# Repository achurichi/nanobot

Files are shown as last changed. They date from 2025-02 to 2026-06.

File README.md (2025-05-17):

# Nanobot

## About This Project

This project is designed for learning ROS 2 on a Jetson Nano-powered robot. It includes various features for perception, control, and simulation, such as:

- **LiDAR** for environment mapping and obstacle detection.
- **Depth Camera** for 3D vision and object recognition.
- **Motor Control with ROS 2 Control** for precise movement and actuation.
- **Navigation** with path planning and obstacle avoidance.
- **Gazebo Simulation** for testing and development in a virtual environment.

Nanobot

## Scripts

The `scripts` folder contains useful scripts to manage the project:

- **`dev.sh`**: Starts the Docker container with the development environment and connects to it.
  Can be called with the following optional parameters:
  - `rebuild`: Forces a rebuild of the Docker image.
  - `restart`: Forces a restart of the Docker container.
  - `<user>@<ip>:<path>`: Connects through SSH to a remote host using the given user, IP, and project path.
    > ⚠️ **Important:** SSH key-based authentication must be set up to enable automatic syncing.  
    > Generate a key pair if you don't already have one:
    >
    > ```bash
    > ssh-keygen
    > ```
    >
    > Then, copy your public key to the Jetson Nano:
    >
    > ```bash
    > ssh-copy-id <user>@<ip>
    > ```
- **`build.sh`**: Builds everything needed to run the real robot or the simulation (if run with the `sim` parameter).
- **`clean.sh`**: Removes the files generated during the build process.
- **`start.sh`**: Starts the robot or the simulation (if run with the `sim` parameter).
- **`monitor.sh`**: Runs rviz and rqt_image_view (call with `sim` parameter if running the simulation).
- **`magnetometer_calibration.py`**: Run it to get the calibration values for the magnetometer. Then update the values in `/ros_ws/src/nanobot_imu/config/imu.yaml`.

## Controlling the Robot

You can control the robot in three different ways:

- **Using a Joystick**  
   If you have a joystick connected via USB, the robot can be controlled directly through it.

  To use the Steam Deck joystick, enable gamepad mode by long-pressing the button with three dashes (≡). You can verify that the joystick is recognized by using the evtest tool.

- **Using the Web App**
  You can control the robot through a web interface. Open a browser and navigate to:  
   `http://<jetson-nano-ip>:5173`

- **Using the Keyboard**  
   To control the robot using the keyboard, run the following command:
  ```bash
   ros2 run teleop_twist_keyboard teleop_twist_keyboard --ros-args -r /cmd_vel:=/cmd_vel_joy
  ```

## Configure the Power Button

Ensure the power button is connected correctly to the Jetson Nano:

- Connect the power button to **Pin 1** and **Pin 2** of the header pins.
- Jumper **Pin 7** and **Pin 8** of the button header pins to disable the auto power on.

Open the `logind.conf` file to adjust the power button settings:

```bash
sudo nano /etc/systemd/logind.conf
```

Add the following lines to the file:

```bash
NAutoVTs=1
ReserveVT=1
HandlePowerKey=poweroff
```

The most reliable way to configure the power button to turn on/off the Jetson Nano is by disabling the graphical user interface (GUI), as GNOME interferes with the button behavior defined in `logind.conf`.

To boot with no GUI:

```bash
sudo systemctl set-default multi-user.target
```

Auto-login is required to allow SSH connections after the system boots up. To enable it, create a directory for custom configurations:

```bash
sudo mkdir /etc/systemd/system/getty@tty1.service.d/
```

Next, open the override configuration file:

```bash
sudo nano /etc/systemd/system/getty@tty1.service.d/override.conf
```

Add the following content to automatically log in your user:

```bash
[Service]
ExecStart=
ExecStart=-/sbin/agetty --noissue --autologin <user-name> %I $TERM
Type=idle
```

Replace `<user-name>` with your actual username.

Finally, reboot the system to apply the changes.

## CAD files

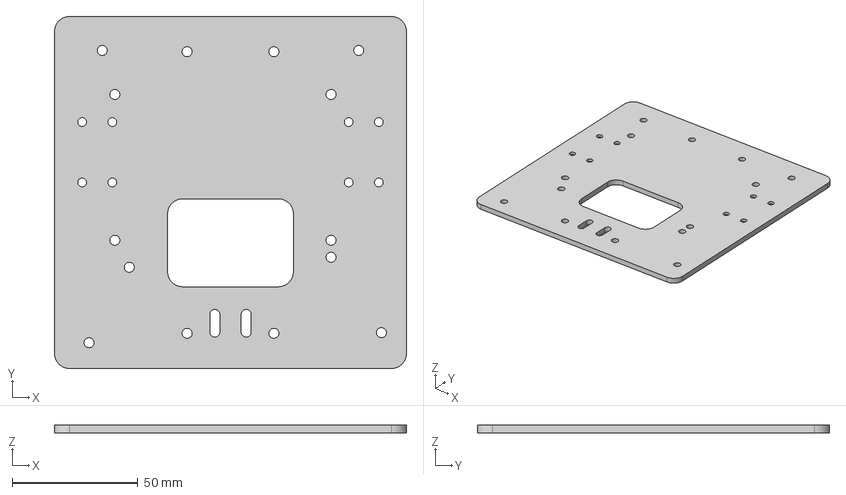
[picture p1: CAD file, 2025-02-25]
3d_parts/base.step
140.0 x 140.0 x 3.00 mm

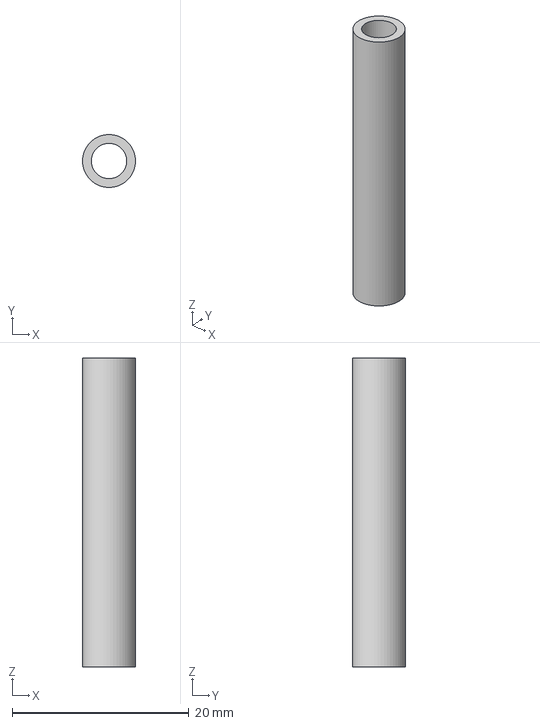
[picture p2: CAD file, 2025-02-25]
3d_parts/spacer_35mm.step
5.99 x 6.00 x 35.0 mm

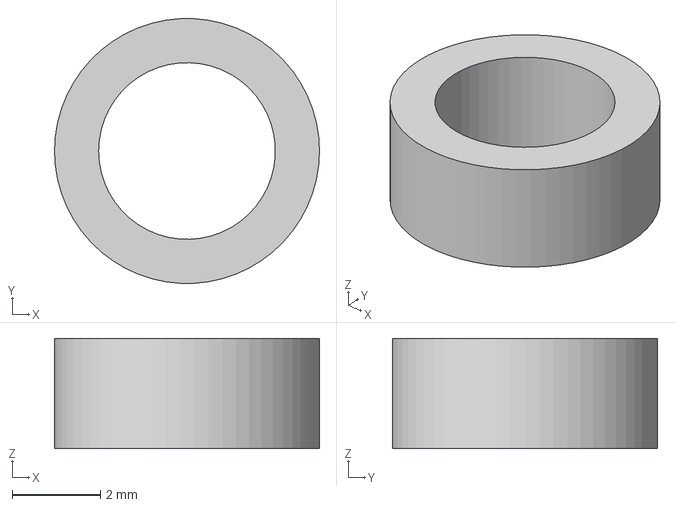
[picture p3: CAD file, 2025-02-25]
3d_parts/spacer_2_5mm.step
6.00 x 5.99 x 2.50 mm

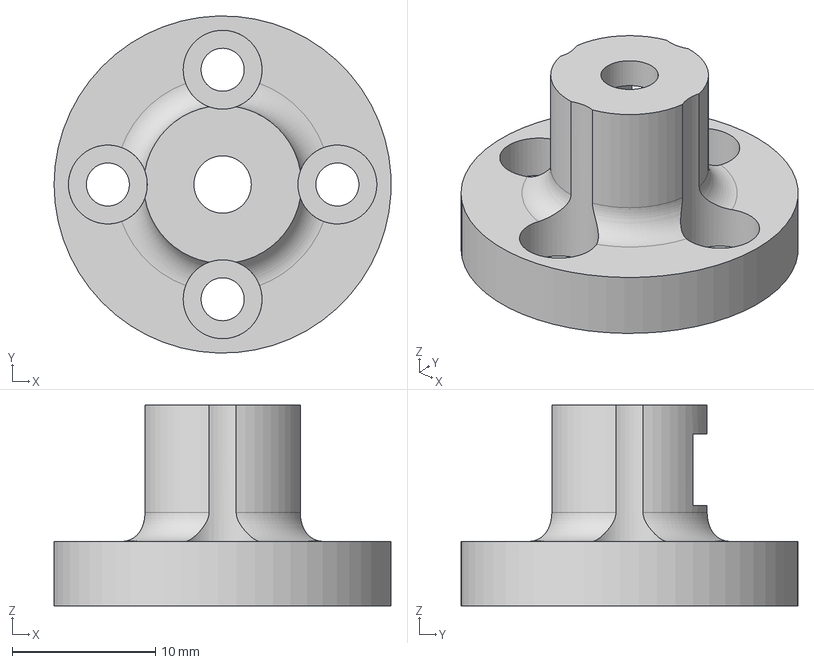
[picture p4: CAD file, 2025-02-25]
3d_parts/wheel_connector.step
23.5 x 23.5 x 14.0 mm

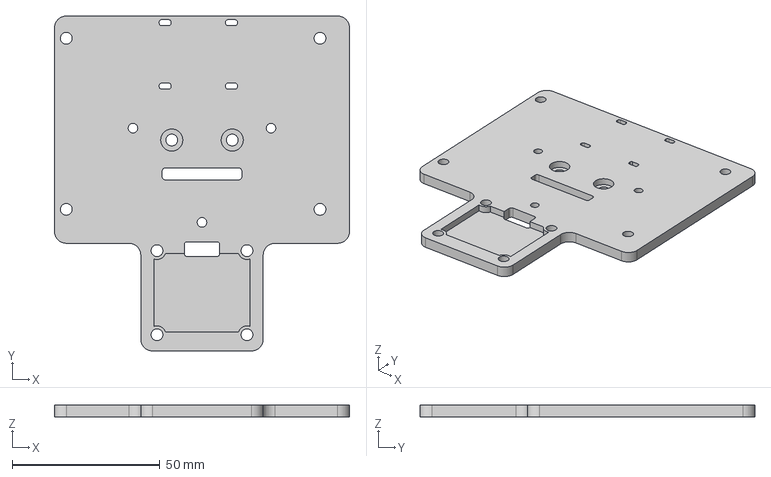
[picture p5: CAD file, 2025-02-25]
3d_parts/top.step
100.0 x 113.5 x 4.00 mm

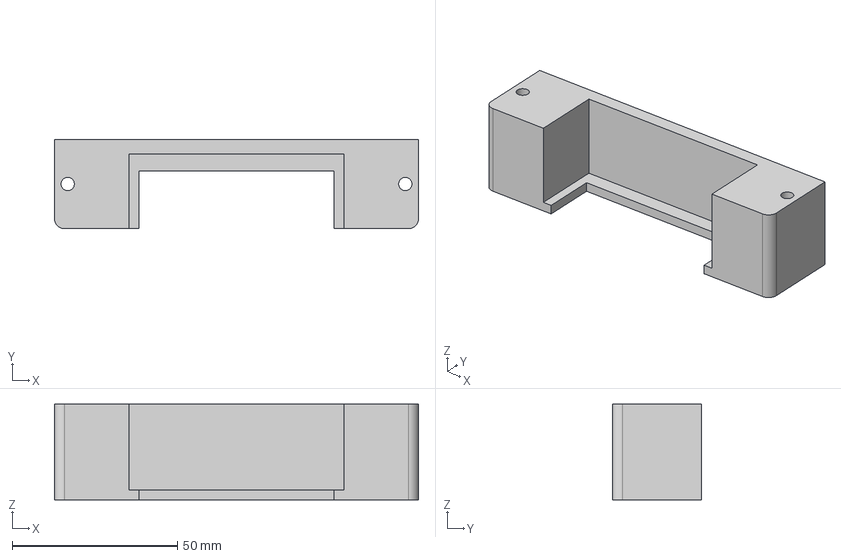
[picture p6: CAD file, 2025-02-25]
3d_parts/battery_holder_front.step
110.0 x 27.0 x 29.0 mm

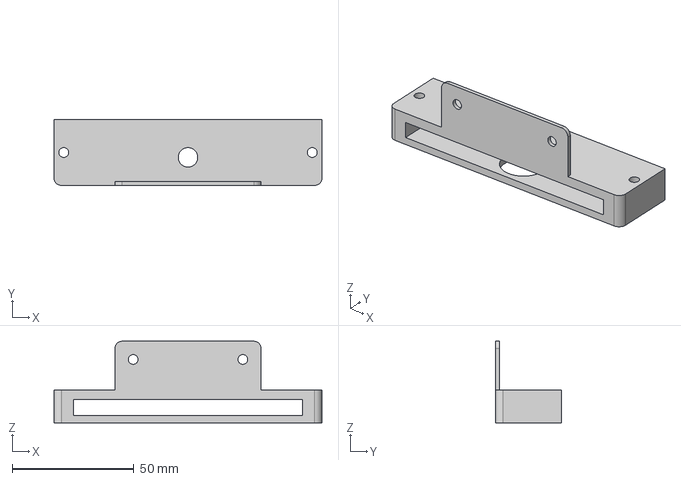
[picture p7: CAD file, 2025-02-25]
3d_parts/camera_holder.step
110.0 x 27.0 x 33.5 mm

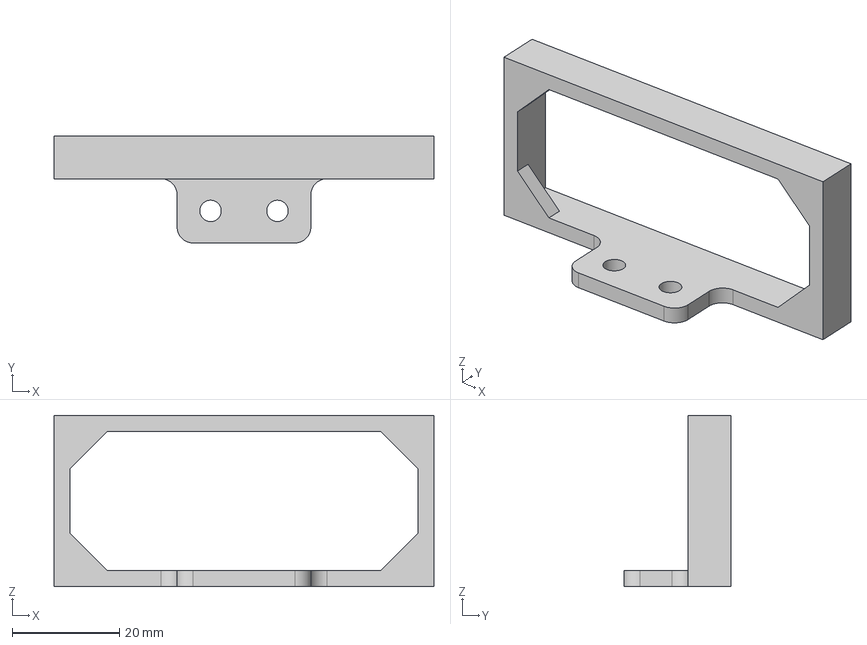
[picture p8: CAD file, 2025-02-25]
3d_parts/battery_holder_back.step
71.0 x 20.0 x 32.0 mm

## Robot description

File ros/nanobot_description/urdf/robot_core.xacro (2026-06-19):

<?xml version="1.0"?>

<robot xmlns:xacro="http://www.ros.org/wiki/xacro" name="nanobot">

  <xacro:include filename="inertial_macros.xacro" />

  <!-- Body dimensions -->
  <xacro:property name="body_x_dim" value="0.152" />
  <xacro:property name="body_y_dim" value="0.0765" />
  <xacro:property name="body_z_dim" value="0.110" />
  <xacro:property name="body_z_offset" value="0.01425" />

  <!-- Wheel dimensions -->
  <xacro:property name="wheel_radius" value="0.033" /> <!-- 66mm diameter -->
  <xacro:property name="wheel_length" value="0.018" />
  <xacro:property name="wheel_x_offset" value="0.05875" />
  <xacro:property name="wheel_y_offset" value="0.00825" />

  <!-- Robot body and wheel mass -->
  <xacro:property name="body_mass" value="1.146" />
  <xacro:property name="wheel_mass" value="0.028" />

  <!-- Moments of intertia of the wheel -->
  <xacro:macro name="inertia_wheel">
    <xacro:inertial_cylinder mass="${wheel_mass}" length="${wheel_length}" radius="${wheel_radius}">
      <origin xyz="0 0 0" rpy="0 0 0" />
    </xacro:inertial_cylinder>
  </xacro:macro>

  <!-- Materials -->

  <material name="yellow">
    <color rgba="1 1 0 1" />
  </material>

  <material name="black">
    <color rgba="0 0 0 1" />
  </material>

  <material name="red">
    <color rgba="1 0 0 1" />
  </material>

  <!-- Links and joints definition -->

  <!-- TODO: Enable base footprint  -->
  <!-- Base footprint -->

  <!-- <joint name="base_joint" type="fixed">
    <parent link="base_footprint"/>
    <child link="base_link"/>
    <origin xyz="0 0 ${wheel_radius}" rpy="0 0 0"/>
  </joint>

  <link name="base_footprint"></link> -->

  <!-- Base link -->

  <link name="base_link"></link>

  <!-- Body -->

  <joint name="body_joint" type="fixed">
    <parent link="base_link" />
    <child link="body_link" />
    <origin xyz="0 0 -${body_z_offset}"/>
  </joint>

  <link name="body_link">
    <visual>
      <origin xyz="0 0 ${body_z_dim/2}" rpy="0 0 0" />
      <geometry>
        <box size="${body_x_dim} ${body_y_dim} ${body_z_dim}" />
      </geometry>
      <material name="yellow" />
    </visual>
    <collision>
      <origin xyz="0 0 ${body_z_dim/2}" rpy="0 0 0" />
      <geometry>
        <box size="${body_x_dim} ${body_y_dim} ${body_z_dim}" />
      </geometry>
    </collision>
    <xacro:inertial_box mass="${body_mass}" x="${body_x_dim}" y="${body_y_dim}" z="${body_z_dim}">
      <origin xyz="0 0 ${body_z_dim/2}" rpy="0 0 0" />
    </xacro:inertial_box>
  </link>

  <gazebo reference="body_link">
    <material>Gazebo/Yellow</material>
  </gazebo>

  <!-- Front left wheel -->

  <joint name="front_left_wheel_joint" type="continuous">
    <parent link="base_link" />
    <child link="front_left_wheel_link" />
    <origin xyz="${wheel_x_offset} ${body_y_dim/2 + wheel_length/2 + wheel_y_offset} 0" rpy="-${pi/2} 0 0" />
    <axis xyz="0 0 1" />
    <limit effort="100" velocity="100" />
    <!-- <dynamics damping="1.0" friction="1.0" /> -->
  </joint>

  <link name="front_left_wheel_link">
    <visual>
      <geometry>
        <cylinder length="${wheel_length}" radius="${wheel_radius}" />
      </geometry>
      <material name="black" />
    </visual>
    <collision>
      <geometry>
        <sphere radius="${wheel_radius}" />
      </geometry>
    </collision>
    <xacro:inertia_wheel />
  </link>

  <gazebo reference="front_left_wheel_link">
    <material>Gazebo/Black</material>
    <!-- <mu1 value="0.2" />
    <mu2 value="0.2" /> -->
  </gazebo>

  <!-- Front right wheel -->

  <joint name="front_right_wheel_joint" type="continuous">
    <parent link="base_link" />
    <child link="front_right_wheel_link" />
    <origin xyz="${wheel_x_offset} -${body_y_dim/2 + wheel_length/2 + wheel_y_offset} 0" rpy="${pi/2} 0 0" />
    <axis xyz="0 0 -1" />
    <limit effort="100" velocity="100" />
    <!-- <dynamics damping="1.0" friction="1.0" /> -->
  </joint>

  <link name="front_right_wheel_link">
    <visual>
      <geometry>
        <cylinder length="${wheel_length}" radius="${wheel_radius}" />
      </geometry>
      <material name="black" />
    </visual>
    <collision>
      <geometry>
        <sphere radius="${wheel_radius}" />
      </geometry>
    </collision>
    <xacro:inertia_wheel />
  </link>

  <gazebo reference="front_right_wheel_link">
    <material>Gazebo/Black</material>
    <!-- <mu1 value="0.2" />
    <mu2 value="0.2" /> -->
  </gazebo>

  <!-- Rear left wheel -->

  <joint name="rear_left_wheel_joint" type="continuous">
    <parent link="base_link" />
    <child link="rear_left_wheel_link" />
    <origin xyz="-${wheel_x_offset} ${body_y_dim/2 + wheel_length/2 + wheel_y_offset} 0" rpy="-${pi/2} 0 0" />
    <axis xyz="0 0 1" />
    <limit effort="100" velocity="100" />
    <!-- <dynamics damping="1.0" friction="1.0" /> -->
  </joint>

  <link name="rear_left_wheel_link">
    <visual>
      <geometry>
        <cylinder length="${wheel_length}" radius="${wheel_radius}" />
      </geometry>
      <material name="black" />
    </visual>
    <collision>
      <geometry>
        <sphere radius="${wheel_radius}" />
      </geometry>
    </collision>
    <xacro:inertia_wheel />
  </link>

  <gazebo reference="rear_left_wheel_link">
    <material>Gazebo/Black</material>
    <!-- <mu1 value="0.2" />
    <mu2 value="0.2" /> -->
  </gazebo>

  <!-- Rear right wheel -->

  <joint name="rear_right_wheel_joint" type="continuous">
    <parent link="base_link" />
    <child link="rear_right_wheel_link" />
    <origin xyz="-${wheel_x_offset} -${body_y_dim/2 + wheel_length/2 + wheel_y_offset} 0" rpy="${pi/2} 0 0" />
    <axis xyz="0 0 -1" />
    <limit effort="100" velocity="100" />
    <!-- <dynamics damping="1.0" friction="1.0" /> -->
  </joint>

  <link name="rear_right_wheel_link">
    <visual>
      <geometry>
        <cylinder length="${wheel_length}" radius="${wheel_radius}" />
      </geometry>
      <material name="black" />
    </visual>
    <collision>
      <geometry>
        <sphere radius="${wheel_radius}" />
      </geometry>
    </collision>
    <xacro:inertia_wheel />
  </link>

  <gazebo reference="rear_right_wheel_link">
    <material>Gazebo/Black</material>
    <!-- <mu1 value="0.2" />
    <mu2 value="0.2" /> -->
  </gazebo>

</robot>

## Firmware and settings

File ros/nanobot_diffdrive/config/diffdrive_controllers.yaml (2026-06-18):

controller_manager:
  ros__parameters:
    update_rate: 30 # Hz

    joint_state_broadcaster:
      type: joint_state_broadcaster/JointStateBroadcaster

    diff_controller:
      type: diff_drive_controller/DiffDriveController

diff_controller:
  ros__parameters:
    left_wheel_names: ['front_left_wheel_joint', 'rear_left_wheel_joint']
    right_wheel_names: ['front_right_wheel_joint', 'rear_right_wheel_joint']

    wheel_separation: 0.1125
    wheel_radius: 0.033
    wheels_per_side: 2

    # estimate_velocity_from_position: false

    # wheel_separation_multiplier: 1.0
    # left_wheel_radius_multiplier: 1.0
    # right_wheel_radius_multiplier: 1.0

    publish_rate: 30.0
    odom_frame_id: odom
    base_frame_id: base_link
    pose_covariance_diagonal : [0.001, 0.001, 0.001, 0.001, 0.001, 0.01]
    twist_covariance_diagonal: [0.001, 0.001, 0.001, 0.001, 0.001, 0.01]

    use_stamped_vel: false

    open_loop: false
    enable_odom_tf: false # Set to true if ekf is disabled

    cmd_vel_timeout: 0.5
    # publish_limited_velocity: true
    # velocity_rolling_window_size: 10

    # Velocity and acceleration limits
    # linear.x.has_velocity_limits: true
    # linear.x.has_acceleration_limits: true
    # linear.x.has_jerk_limits: false
    # linear.x.max_velocity: 1.0
    # linear.x.min_velocity: -1.0
    # linear.x.max_acceleration: 1.0
    # linear.x.max_jerk: 0.0
    # linear.x.min_jerk: 0.0

    # angular.z.has_velocity_limits: true
    # angular.z.has_acceleration_limits: true
    # angular.z.has_jerk_limits: false
    # angular.z.max_velocity: 1.0
    # angular.z.min_velocity: -1.0
    # angular.z.max_acceleration: 1.0
    # angular.z.min_acceleration: -1.0
    # angular.z.max_jerk: 0.0
    # angular.z.min_jerk: 0.0

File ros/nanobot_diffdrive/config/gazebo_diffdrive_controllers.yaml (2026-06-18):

controller_manager:
  ros__parameters:
    update_rate: 30
    use_sim_time: true

    diff_controller:
      type: diff_drive_controller/DiffDriveController

    joint_broad:
      type: joint_state_broadcaster/JointStateBroadcaster

diff_controller:
  ros__parameters:
    publish_rate: 30.0 # You can set this higher than the controller manager update rate, but it will be throttled
    base_frame_id: base_link

    left_wheel_names: ['front_left_wheel_joint', 'rear_left_wheel_joint']
    right_wheel_names: ['front_right_wheel_joint', 'rear_right_wheel_joint']

    wheel_separation: 0.1125
    wheel_radius: 0.033
    wheels_per_side: 2

    use_stamped_vel: false

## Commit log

2025-02-24 Use ros container for jetson
2025-02-25 Add 3d parts
    [base.step, battery_holder_back.step, battery_holder_front.step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]
2025-02-26 Update dockerfile and robot description
    [gazebo_control.xacro, inertial_macros.xacro, robot.urdf.xacro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]
2025-02-26 Add simulation
    [gazebo_diffdrive_controllers.yaml, gazebo_ros2_control.xacro, robot.urdf.xacro]
2025-02-26 Add config for local and nano development
    [robot.urdf.xacro]
2025-02-28 Use ros2 control
    [robot.urdf.xacro]
2025-02-28 Use ros2 control with custom hardware interface
    [diffdrive_controllers.yaml, gazebo_control.xacro, gazebo_diffdrive_controllers.yaml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]
2025-02-28 Refactor control package
    [diffdrive_controllers.yaml, gazebo_diffdrive_controllers.yaml, gazebo_ros2_control.xacro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]
2025-02-28 Rename packages to avoid conflicts
    [inertial_macros.xacro, robot.urdf.xacro, robot_core.xacro]
2025-03-01 Add FastDDS discovery server
    [gazebo_diffdrive_controllers.yaml]
2025-03-02 Make open loop
    [diffdrive_controllers.yaml]
2025-03-02 Improve robot sizes
    [diffdrive_controllers.yaml, gazebo_diffdrive_controllers.yaml, robot_core.xacro]
2025-03-02 Add lidar to sim
    [gazebo_diffdrive_controllers.yaml, lidar.xacro, robot.urdf.xacro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]
2025-03-03 Add ldlidar
    [lidar.xacro, ros2_control.xacro]
2025-03-03 Fix lidar simulation
    [lidar.xacro]
2025-03-04 Add camera to sim
    [camera.xacro, robot.urdf.xacro]
2025-03-05 Add camera to the robot
2025-03-10 Add imu
    [imu.xacro, robot.urdf.xacro, robot_core.xacro]
2025-03-11 Calibrate imu magnetomenter
2025-03-11 Improve lidar nodes. Don't use cyclonedds_profile
2025-03-12 Add depth camera
    [camera.xacro]
2025-03-12 Use depth camera in simulation
    [camera.xacro]
2025-03-13 Use ignition gazebo
    [boxes.sdf, gazebo_ros2_control.xacro]
2025-03-13 Update gazebo plugins
    [boxes.sdf, camera.xacro, gazebo_diffdrive_controllers.yaml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]
2025-03-17 Report position to the controller
    [ros2_control.xacro]
2025-03-17 Testing slam
    [robot_core.xacro]
2025-03-18 Add room map
    [robot_core.xacro]
2025-03-20 Add ekf filter to combine diff drive odometry and imu data
    [diffdrive_controllers.yaml]
2025-03-21 Update camera config decrese odom frecuency
    [diffdrive_controllers.yaml, gazebo_diffdrive_controllers.yaml]
2025-03-25 Allow camera with gpu
    [camera.xacro]
2025-03-25 Move gpu camera logic inside the camera package
2025-04-03 Use BNO085 driver
    [imu.xacro]
2025-05-20 Add depth camera to simulation
    [camera.xacro]
2025-05-21 Disable the imu. Don't use open loop on the diff controller to decrease the rotation shift
    [diffdrive_controllers.yaml]
2026-04-12 Implement new Dockerfile, improve camera node
2026-04-13 Adapt description and diffdrive controller to new dimensions
    [camera.xacro, diffdrive_controllers.yaml, gazebo_diffdrive_controllers.yaml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]
2026-04-15 Folder restructure
    [boxes.sdf, camera.xacro, diffdrive_controllers.yaml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]
2026-04-29 Enable IMU, remove calibration for old chip.
2026-05-07 Fix imu issues, enable ekf
    [diffdrive_controllers.yaml, imu.xacro, robot.urdf.xacro]
2026-05-08 IMU improvements
2026-05-09 Add diffdrive support for multiple wheels
    [diffdrive_controllers.yaml, gazebo_diffdrive_controllers.yaml, gazebo_ros2_control.xacro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]
2026-05-09 Remove old camera files
2026-06-18 Update sizes and enable front wheels
    [camera.xacro, diffdrive_controllers.yaml, gazebo_diffdrive_controllers.yaml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]
2026-06-19 Add suport to rplidar c1
    [lidar.xacro, robot.urdf.xacro, robot_core.xacro]
